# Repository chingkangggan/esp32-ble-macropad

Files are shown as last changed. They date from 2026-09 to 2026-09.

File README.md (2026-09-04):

# ESP32 BLE Macropad

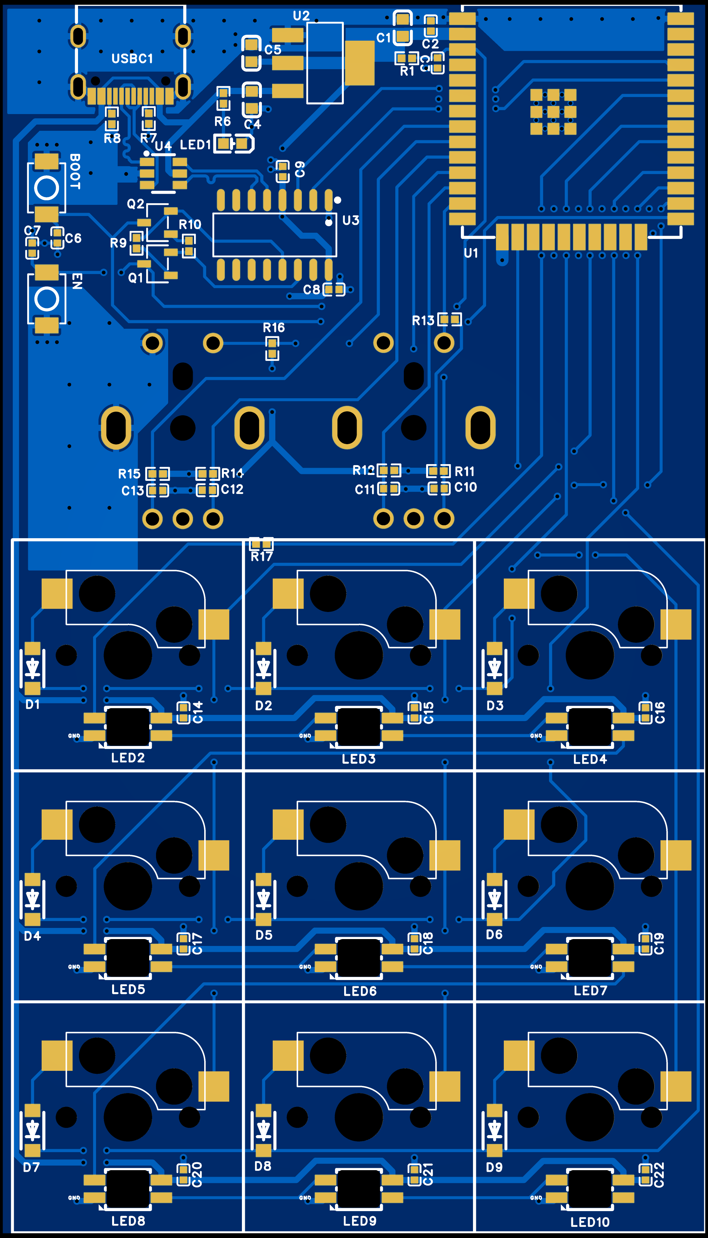
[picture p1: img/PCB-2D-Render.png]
PCB-2D-Render


## Overview
A custom 3x3 hardware macropad firmware powered by an ESP32 micro-controller, featuring dual rotary encoders, persistent NVS flash storage, and interactive Serial CLI configuration.

---

## Key Features

* **BLE Human Interface Device (HID):** Emulates a wireless Bluetooth keyboard using the `BleKeyboard` library.
* **3x3 Matrix Keypad:** Utilizes dynamic row-column scanning with multi-key modifier combination detection (allows declaring keys as either modifier holdings or action triggers).
* **Combo Keys & Layering Support** Allows physical pad buttons to be configured as Modifiers or Action keys. Supports holding single or multiple modifier keys on the pad to trigger layered multi-key macro combinations (up to 5 output HID keys per combo).
* **Dual Rotary Encoders:** Configured via `ESP32Encoder` using hardware PCNT tracking for volume controls, media navigation, and mute toggles.
* **On-the-Fly Serial CLI:** Allows users to map custom keyboard shortcuts, configure modifier rules, and monitor button matrices directly via the Arduino Serial Monitor without re-flashing.
* **Non-Volatile Storage (NVS):** Automatically saves modifier states and shortcut combination maps to onboard flash memory using `Preferences.h`.

---

## Hardware

### Schematics

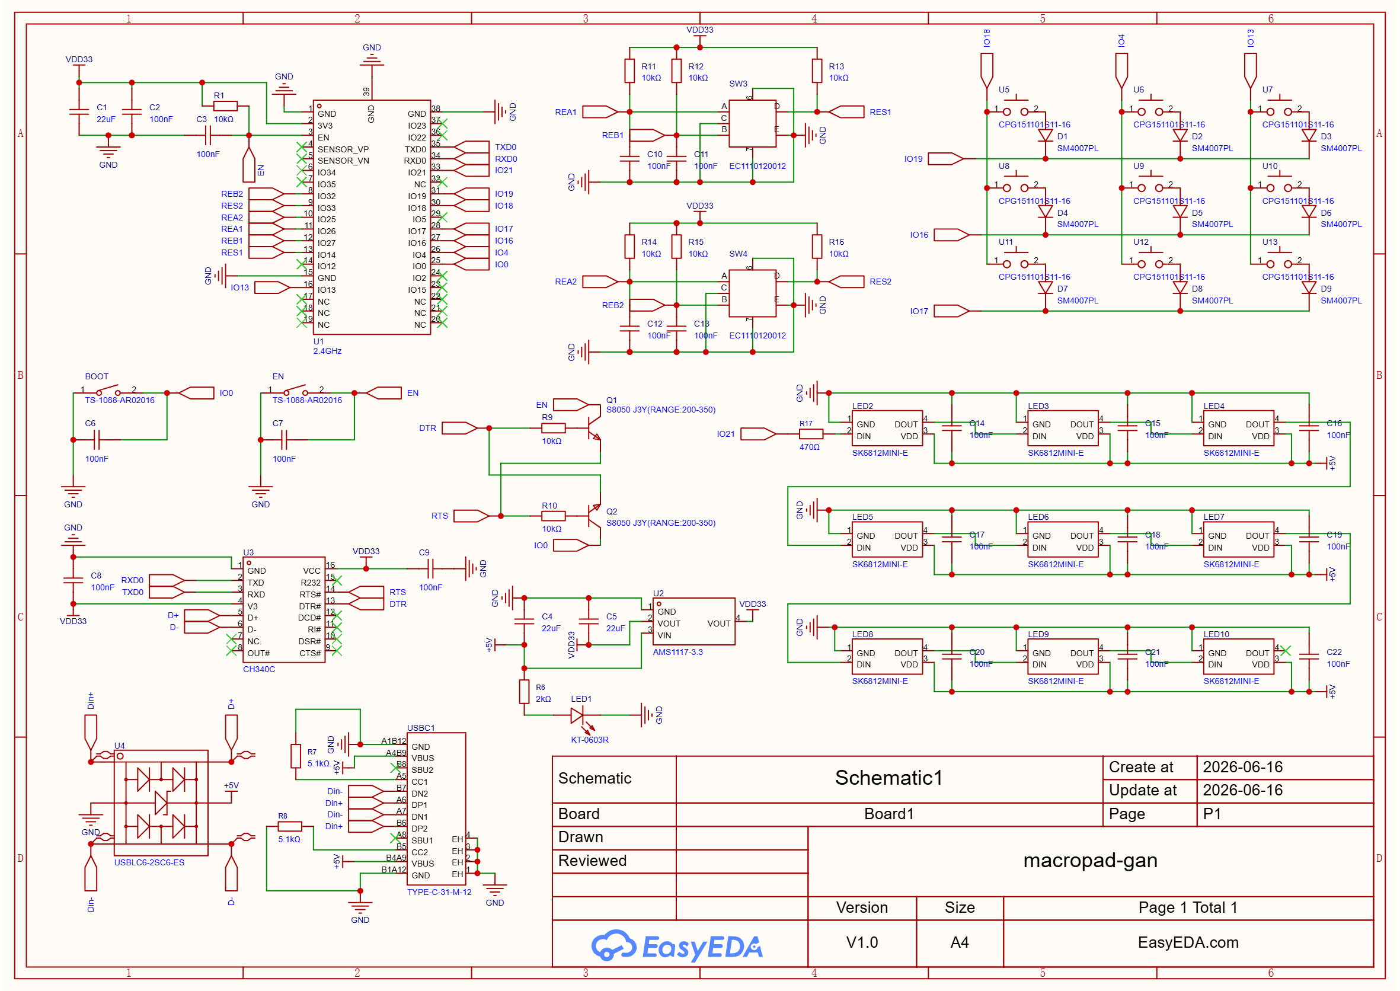
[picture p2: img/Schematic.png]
Schematics


> **Core Circuit Summary:** USB-C powered ESP32 macropad featuring an auto-reset UART flashing circuit, a 3x3 key matrix with anti-ghosting diodes, dual rotary encoders with pushbuttons, and a daisy-chained SK6812MINI-E addressable RGB LED array (optional).

---

#### **1. Power & USB Interface**

* **USB Interface:** USB-C connector protected with a USBLC6-2SC6-ES ESD protection array on the $D+ / D-$ lines.
* **Power Regulation:** Input $+5\text{V}$ from USB-C feeds an AMS1117-3.3 linear regulator to supply a stable $3.3\text{V}$ rail ($\text{VDD33}$) to the microcontroller.
* **Filtering & Indication:** $22\mu\text{F}$ and $100\text{nF}$ decoupling capacitors on the supply rails, featuring a dedicated red power indicator LED (LED1).

---

#### **2. Microcontroller & USB-to-UART Bridge**

* **Core Unit:** ESP32-WROOM module handles primary processing and wireless capabilities.
* **UART Communication:** CH340C USB-to-UART converter interfaces USB data directly to ESP32 hardware serial ports ($\text{TXD0} / \text{RXD0}$).
* **Auto-Reset / Flashing Circuit:** Dual S8050 NPN transistor circuit ($Q1, Q2$) driven by $\text{DTR} / \text{RTS}$ for automated flashing, backed by manual BOOT ($\text{IO0}$) and RESET ($\text{EN}$) tactile buttons with RC debouncing.

---

#### **3. Key Matrix Pinout (3x3 Grid)**

| Row / Line | Key Switches | Anti-Ghosting Diodes |
| --- | --- | --- |
| **Row 1** | U5, U6, U7 | D1, D2, D3 (SM4007PL) | 
| **Row 2** | U8, U9, U10 | D4, D5, D6 (SM4007PL) | 
| **Row 3** | U11, U12, U13 | D7, D8, D9 (SM4007PL) |

---

#### **4. Subsystem Breakdown**

**Dual Rotary Encoders (SW3 & SW4)**

* **SW3:** Encoder channels $A / B$ connected to **REA1** ($\text{IO25}$) & **REB1** ($\text{IO32}$), with integrated switch on **RES1** ($\text{IO14}$).
* **SW4:** Encoder channels $A / B$ connected to **REA2** ($\text{IO27}$) & **REB2** ($\text{IO33}$), with integrated switch on **RES2** ($\text{IO12}$).
* **Debouncing & Pull-ups:** Filtered with $10\text{k}\Omega$ pull-up resistors to $\text{VDD33}$ and $100\text{nF}$ RC capacitors on output channels.

**Addressable RGB LED Matrix** (Optional)

* **LED Array:** 9x SK6812MINI-E RGB LEDs daisy-chained from **IO21** via a $470\Omega$ series resistor.
* **Bypass Filtering:** Individual $100\text{nF}$ decoupling capacitors ($C14 - C22$) placed at every LED $+5\text{V}$ power pin.

---

### PCB Layout

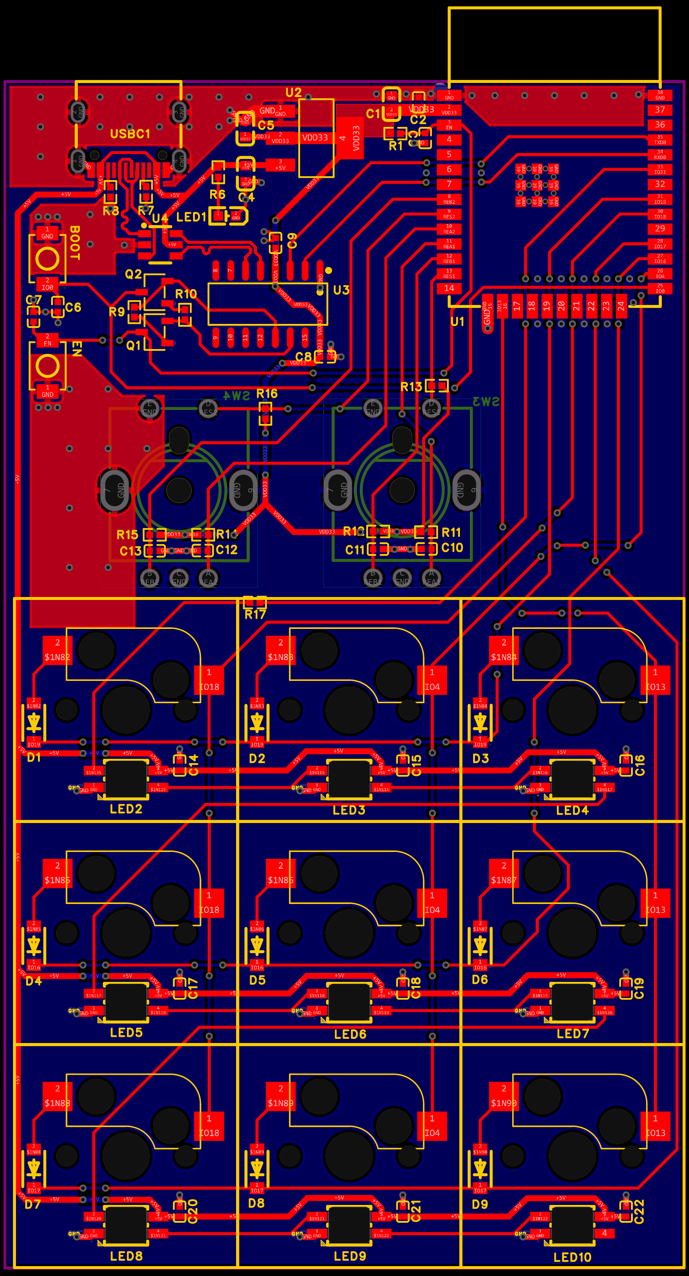
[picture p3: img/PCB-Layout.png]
PCB-Layout


> **Board Layout Overview:** A 2-layer, high-density layout featuring a distinct functional split: dense SMD processing/interface circuitry in the top section, and a spacious 3x3 key grid with integrated per-key SK6812MINI-E reverse-mount/underglow LEDs (optional) across the bottom. The board is designed upside down so most of the components are on the top layer.

---

#### **1. Board Specifications & Design Rules**

* **Layer Count:** 2-Layer Board (Top Layer: Red traces/pours, Bottom Layer: Blue traces/pours)
* **Form Factor:** Compact Macropad layout featuring 9 key switch footprints and dual rotary encoders
* **Copper Pours:** Dedicated ground ($GND$) planes on top and bottom layers for EMI shielding and thermal dissipation

---

#### **2. Layout & Zone Division**

**Processing & Power Zone (Top Half)**

* **USB-C & Interface:** USB-C connector situated at top-left with short, differential pair length-matched trace routing to ESD protection ($U4$) and CH340C ($U3$) serial bridge.
* **Voltage Regulator:** AMS1117-3.3 ($U2$) placed directly near the main power input with wide $+5\text{V}$ and $\text{VDD33}$ copper traces to handle current flow.
* **Control Buttons:** Tactile BOOT and RESET switches placed along the left board edge for quick flashing access.
* **Microcontroller Position:** ESP32-WROOM module ($U1$) occupies the top-right quadrant, oriented with its PCB antenna area positioned along the board edge to optimize wireless signal performance.

**Interactive Matrix Zone (Bottom Half)**

* **Key Matrix Layout:** Uniform $3\times3$ grid housing hot-swap / PCB-mount key switch footprints.
* **Component Placement:** Each key node integrates a dedicated anti-ghosting diode ($D1 - D9$) and a local $100\text{nF}$ bypass capacitor ($C14 - C22$).
* **RGB LED Integration:** SK6812MINI-E addressable LEDs ($LED2 - LED10$) mounted directly under each switch position with daisy-chained data routing running horizontally across the bottom layer.

---

#### **3. Routing & Signal Integrity Highlights**

* **Traces & Vias:** Heavy use of stitching vias around high-current supply nodes and ground planes to reduce loop inductance.
* **Bypass Capacitor Proximity:** Decoupling caps ($C1 - C5$, $C10 - C13$, $C14 - C22$) are placed immediately adjacent to their respective IC and LED power pins.
* **Signal Isolation:** Direct, clean trace runs on top/bottom layers cleanly separating high-speed USB data lines from low-frequency switch matrix lines.

---

## Firmware

```
                               +-----------------------------+
                               |        main.cpp / loop      |
                               +--------------+--------------+
                                              |
      +---------------------------------------+---------------------------------------+
      |                                       |                                       |
      v                                       v                                       v
+-----------------------+           +-----------------------+           +-----------------------+
|   handleSerial()      |           |     readMatrix()      |           |  ESP32Encoder / PCNT  |
|                       |           |                       |           |                       |
| Reads Serial stream   |           | Active-low GPIO scan  |           | Tracks Hardware       |
| into string buffer    |           | updates 16-bit mask   |           | Rotary Encoder steps  |
+-----------+-----------+           +-----------+-----------+           +-----------+-----------+
            |                                   |                                   |
            | Passes raw                        | Passes button state               | Rotated / Clicked
            | command lines                     | bitmask on change                 |
            v                                   v                                   v
+-----------------------------------------------------------------------------------------------+
|                                  Shortcut_Manager (Singleton)                                 |
|                                                                                               |
|  +--------------------------------+   +----------------------------------------------------+  |
|  |       parseCommand()           |   |                   update()                         |  |
|  |                                |   |                                                    |  |
|  | Parses CLI strings:            |   | Detects keypress state changes (pressed & !was)    |  |
|  |  - HELP / SHOW                 |   | Calls sendShortcut(currentButtonState)             |  |
|  |  - MODIFIER <btn>:<0/1>        |   +-------------------------+--------------------------+  |
|  |  - SET <combo>:<key_seq>       |                             |                             |
|  +---------------+----------------+                             | Output HID Keycodes         |
|                  |                                              |                             |
|                  | Syncs changes                                v                             |
|                  v                                +---------------------------+               |
|  +--------------------------------+               |       BleKeyboard         |               |
|  |    ESP32 Preferences (NVS)     |               |                           |               |
|  |                                |               | Sends keypresses/releases |               |
|  | Writes mod_mask & shortcuts    |               | wirelessly over Bluetooth |               |
|  | array to flash memory          |               +-------------+-------------+               |
|  +--------------------------------+                             |                             |
+-----------------------------------------------------------------|-----------------------------+
                                                                  |
                                                                  v
                                                     +--------------------------+
                                                     |       Host Computer      |
                                                     +--------------------------+
```

> Built on the Arduino framework for ESP32, integrating BLE HID keyboard functionality (`BleKeyboard`), hardware PCNT rotary tracking (`ESP32Encoder`), non-volatile storage configuration saving (`Preferences`), and a thread-safe Singleton manager for dynamic matrix key mapping.

---

### 1. Matrix Scanning Mechanism (`readMatrix`)

The 3x3 key matrix relies on standard active-low column scanning using internal GPIO pull-ups to track active key states efficiently into a single 16-bit bitmask (`buttonState`).

* **Pin Configuration:** Rows are assigned to outputs (`19`, `16`, `17`), while Columns use internal pull-up inputs (`13`, `4`, `18`).
* **Active-Low Scanning Loop:**
    1. The scanner iterates through each row, pulling it `LOW` while driving all inactive rows to floating high-impedance (`INPUT`).
    2. Columns are sampled using `digitalRead()`. A logic `LOW` on a column pin signals a closed switch connection.
    3. Pressed keys are recorded directly into an integer bitfield via bitwise shift operations: `currentScanState |= (1 << (j + i * ROWS))`.

* **State Change Detection:** Key evaluation triggers exclusively when the sampled state bitmask differs from `lastButtonState`, minimizing unnecessary polling overhead.

---

### 2. Singleton Pattern: `Shortcut_Manager`

The macro management system uses a thread-safe C++ Singleton pattern to guarantee a single global instance for non-volatile key mappings, serial console interactions, and HID output handling.

* **Singleton Implementation:** Encapsulates initialization logic with a private constructor and deleted copy/assignment operators (`Shortcut_Manager(const Shortcut_Manager&) = delete;`). The global reference is accessed safely via:
```cpp
Shortcut_Manager& manager = Shortcut_Manager::getInstance();

```

* **Bitfield State Engine:** Manages combinations by mapping the 9 physical matrix keys to a bitfield mask (`isKeyModifierMask`) and an array of target HID sequences (`shortcuts[TOTAL_COMBINATIONS][SC_LEN_MAX]`).
* **NVS Storage Integration:** Leverages ESP32 `Preferences` to write modifier masks and multidimensional macro mapping arrays directly into non-volatile Flash storage, retaining custom keybindings across power cycles.
* **CLI Engine:** Includes a built-in Serial terminal interpreter supporting runtime macro management via `HELP`, `SHOW`, `MODIFIER <btn>:<0/1>`, and `SET <combo>:<keys>` commands.

---

### 3. Hardware Encoders & BLE HID Integration

* **Hardware Pulse Counter (PCNT):** Uses `ESP32Encoder` configured with `attachHalfQuad` to handle quadrature decoding in hardware without losing pulses during loop execution.
* **Rotary Media Controls:**
    * Encoder 1 directly emits `KEY_MEDIA_VOLUME_UP` / `KEY_MEDIA_VOLUME_DOWN` keycodes, with its shaft button sending `KEY_MEDIA_MUTE`.
    * Encoder 2 tracks hardware position steps for custom user extensions.

* **BLE Connectivity:** Emulates a standard Bluetooth LE keyboard (`BleKeyboard`), broadcasting parsed multi-key sequences and consumer control signals wirelessly to connected host devices.

---

## Setup & Assembly Guide

### 1. PCB Ordering & Assembly

1. Download the latest release package containing the `Gerber`, `BOM` (Bill of Materials), and `CPL` (Component Placement List) files.
2. Upload the Gerber `.zip` file to your preferred PCB fabricator (e.g., JLCPCB, PCBWay).
3. Enable **SMD Assembly** service:
    * Upload `BOM.csv` and `CPL.csv` when prompted for component placement (covers the core SMD components and CH340C bridge).
    * Verify part orientations against the silkscreen preview before finalizing the order.

4. Once the board arrives, solder the remaining components:
    * **Required Through-Hole Parts:** EC11 Rotary Encoders are **not included** in the default BOM/CPL and require manual sourcing and soldering.
    * **Optional RGB Lighting:** The PCB layout supports SK6812MINI-E reverse-mount LEDs, but they are **not included** in the default BOM/CPL or stock firmware. If you choose to hand-solder them, you will need to add custom LED driving logic to your code.

---

### 2. Firmware Setup (PlatformIO)

1. **Clone the Repository:**
```bash
git clone https://github.com/chingkangggan/esp32-ble-macropad.git
cd esp32-ble-macropad/firmware

```

2. **Open in PlatformIO:**
* Open **VS Code** with the **PlatformIO IDE** extension installed.
* Select **File > Open Folder** and navigate directly to the `firmware` directory.
* *Note: All library dependencies (`ESP32 BLE Keyboard`, `ESP32Encoder`) and board configurations are already defined in `platformio.ini`, so no manual setup is required.*

3. **Flash the Firmware:**
* Connect your board via USB-C.
* Put the ESP32 into bootloader mode if auto-reset isn't triggered (hold `BOOT`, tap `RESET`, release `BOOT`).
* Click **PlatformIO: Upload** in the bottom toolbar, or run:
```bash
pio run --target upload

```

4. **Configure via Serial:**
* Open the PlatformIO Serial Monitor set to `115200` baud.
* Type `HELP` to view available CLI commands for assigning key combinations and modifiers.

---

## Serial CLI Configuration

The onboard Serial Command Line Interface allows real-time macro configuration, modifier toggling, and layout inspection directly through the PlatformIO or Arduino Serial Monitor without re-flashing the firmware.

### **1. Connection Settings**

* **Baud Rate:** `115200`
* **Line Ending:** Both `NL` & `CR` (`\r\n`)

---

### **2. Available Commands**

| Command | Syntax / Parameters | Description | Example |
| --- | --- | --- | --- |
| **`HELP`** | `HELP` | Displays the help menu with all available commands. | `HELP` |
| **`SHOW`** | `SHOW` | Prints the current modifier assignments and active macro combos stored in NVS flash. | `SHOW` |
| **`MODIFIER`** | `MODIFIER <btn_index>:<0/1>` | Configures a pad key as a Modifier holding key (`1`) or a standard Action trigger (`0`). | `MODIFIER 1:1` |
| **`SET`** | `SET <combo_mask>:<key_seq>` | Binds a single key or modifier combo bitmask to a sequence of up to 5 HID keycodes. | `SET 1+2:LCTRL+C` |

---

### **3. Step-by-Step Configuration Examples**

* **Setting a Dedicated Modifier Key:**
To turn Key `1` into a held layer modifier key:
```text
> MODIFIER 1:1
[OK] Key 1 set as MODIFIER.

```

* **Mapping a Multi-Key Macro Combo:**
To map holding Key `1` (Modifier) while pressing Key `2` to trigger `Ctrl + C` (Copy):
```text
> SET 1+2:LCTRL+C
[OK] Combo (1+2) mapped to [LCTRL, C]. Saved to NVS.

```

* **Inspecting Saved Layouts:**
```text
> SHOW
--- Active Configurations ---
Modifiers Bitmask : 0x0002 [Key 1]
Combos:
  [Key 1 + Key 2] -> LCTRL + C
  [Key 0]        -> KEY_MEDIA_VOLUME_UP

```

---

## 3D Printed Enclosure

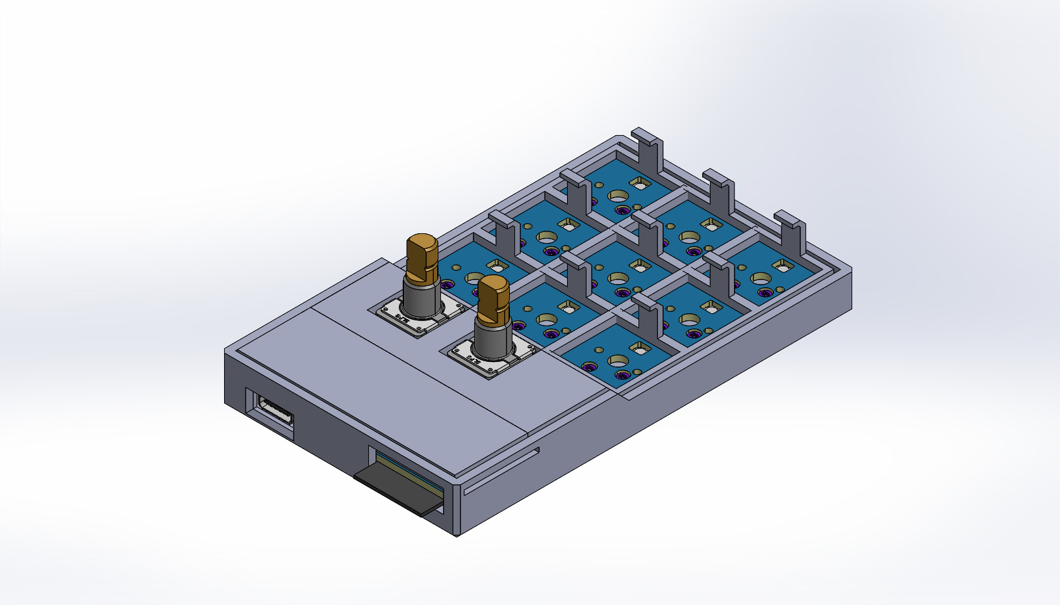
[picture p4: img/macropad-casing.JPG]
Macropad Casing


> **Design Overview:** A custom, low-profile case designed in SolidWorks to house the populated PCB and mechanical switches securely. The enclosure features precise cutouts for the USB-C port, dual rotary encoders, and top-side tactile buttons.

---

### 1. Printing the STL Files

All 3D printable model files are located in the `/mechanical` folder.

| File | Quantity | Recommended Material | Description |
| --- | --- | --- | --- |
| **`top-cover.stl`** | 1 | PLA / PETG | Top plate securing the cover plate to the bottom enclosure |
| **`cover-plate.stl`** | 1 | PLA / PETG | Securing the PCB into the enclosure |
| **`macropad-enclosure.stl`** | 1 | PLA / PETG  | Main housing for PCB |

**Recommended Slicer Settings:**

* **Layer Height:** `0.2mm`
* **Infill:** `15% - 20%` (Grid or Gyroid)
* **Supports:** None required (designed for flat print orientations)

---

### 2. Final Assembly

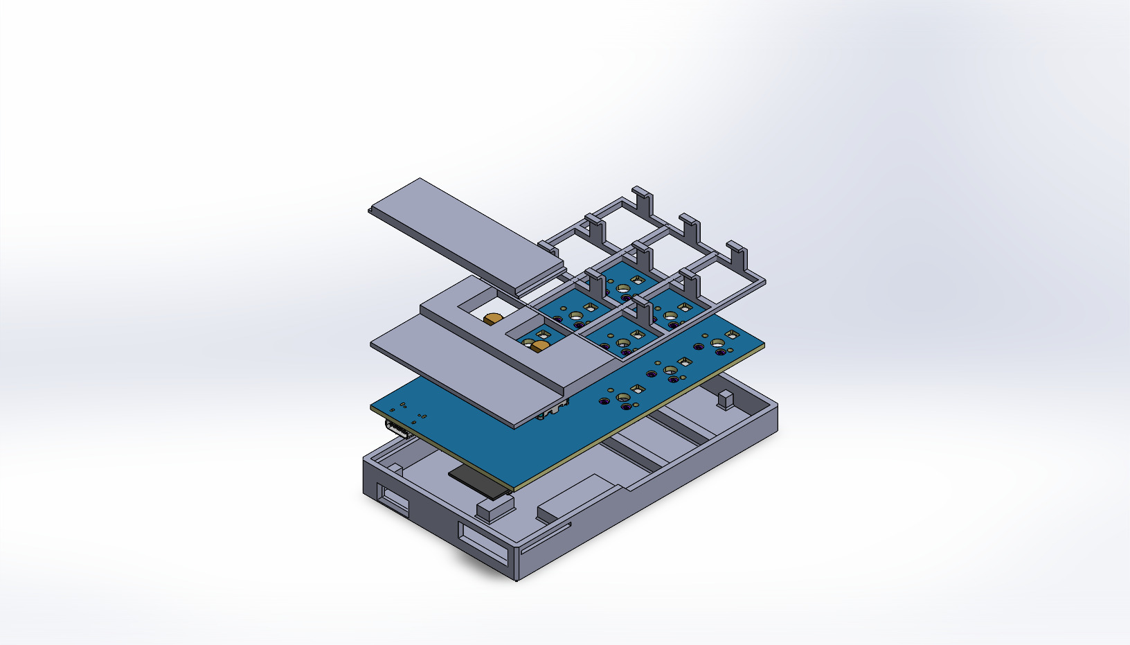
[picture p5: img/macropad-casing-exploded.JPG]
Macropad Casing


1. **Place PCB in enclosure:** Insert PCB into `macropad-enclosure.stl`.
2. **Cover Plate:** Place `cover-plate.stl` on top of the PCB to secure it against the enclosure.
3. **Snap Fit Top Cover:** Snap fit `top-cover.stl` to secure the cover plate against the enclosure.

---

## Credits

Designed and developed by the **Technical Team** of the **IEEE Student Branch (26/27)** at the **University of Nottingham Malaysia**, as part of the **Sparks Initiative 26/27**.

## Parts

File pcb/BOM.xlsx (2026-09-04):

No. | Quantity | Comment | Designator | Footprint | Value | Manufacturer Part | Manufacturer | Supplier Part | Supplier
1 | 2 | TS-1088-AR02016 | BOOT,EN | SW-SMD_L3.9-W3.0-P4.45 |  | TS-1088-AR02016 | XUNPU(讯普) | C720477 | LCSC
2 | 3 | 22uF | C1,C4,C5 | C0603 | 22uF | CL10A226MQ8NRNC | SAMSUNG(三星) | C59461 | LCSC
3 | 19 | 100nF | C2,C3,C6,C7,C8,C9,C10,C11,C12,C13,C14,C15,C16,C17,C18,C19,C20,C21,C22 | C0402 | 100nF | CL05B104KO5NNNC | SAMSUNG(三星) | C1525 | LCSC
4 | 9 | SM4007PL | D1,D2,D3,D4,D5,D6,D7,D8,D9 | SOD-123F_L2.8-W1.8-LS3.7-RD |  | SM4007PL | MDD(辰达半导体) | C64898 | LCSC
5 | 1 | KT-0603R | LED1 | LED-SMD_L1.6-W0.8-R-RD |  | KT-0603R | KENTO | C2286 | LCSC
6 | 9 | SK6812MINI-E | LED2,LED3,LED4,LED5,LED6,LED7,LED8,LED9,LED10 | LED-SMD_4P-L3.2-W2.8-LS5.9_SK6812MINI-E |  | SK6812MINI-E | 欧思科光电 | C5149201 | LCSC
7 | 2 | S8050 J3Y(RANGE:200-350) | Q1,Q2 | SOT-23-3_L3.0-W1.7-P0.95-LS2.9-BR |  | S8050 J3Y(RANGE:200-350) | CJ(江苏长电/长晶) | C2146 | LCSC
8 | 9 | 10kΩ | R1,R9,R10,R11,R12,R13,R14,R15,R16 | R0402 | 10kΩ | 0402WGF1002TCE | UNI-ROYAL(厚声) | C25744 | LCSC
9 | 1 | 2kΩ | R6 | R0402 | 2kΩ | 0402WGF2001TCE | UNI-ROYAL(厚声) | C4109 | LCSC
10 | 2 | 5.1kΩ | R7,R8 | R0402 | 5.1kΩ | 0402WGF5101TCE | UNI-ROYAL(厚声) | C25905 | LCSC
11 | 1 | 470Ω | R17 | R0402 | 470Ω | 0402WGF4700TCE | UNI-ROYAL(厚声) | C25117 | LCSC
12 | 2 | EC1110120012 | SW3,SW4 | SW-TH_EC1110120012 |  | EC1110120012 | ALPSALPINE(阿尔卑斯阿尔派) | C2687281 | LCSC
13 | 1 | 2.4GHz | U1 | WIFI-SMD_ESP32-WROOM-32E | 2.4GHz | ESP32-WROOM-32E-N8 | ESPRESSIF(乐鑫) | C701342 | LCSC
14 | 1 | AMS1117-3.3 | U2 | SOT-223-3_L6.5-W3.4-P2.30-LS7.0-BR |  | AMS1117-3.3 | Advanced Monolithic Systems | C6186 | LCSC
15 | 1 | CH340C | U3 | SOP-16_L10.0-W3.9-P1.27-LS6.0-BL |  | CH340C | WCH(南京沁恒) | C84681 | LCSC
16 | 1 | USBLC6-2SC6-ES | U4 | SOT-23-6_L2.9-W1.6-P0.95-LS2.8-BR |  | USBLC6-2SC6-ES | ElecSuper(静芯) | C5180249 | LCSC
17 | 9 | CPG151101S11-16 | U5,U6,U7,U8,U9,U10,U11,U12,U13 | MX-Hotswap-1u-Antishear |  | CPG151101S11-16 | HanElectricity(瀚源) | C41430893 | LCSC
18 | 1 | TYPE-C-31-M-12 | USBC1 | USB-C_SMD-TYPE-C-31-M-12_1 |  | TYPE-C-31-M-12 | 韩国韩荣 | C165948 | LCSC

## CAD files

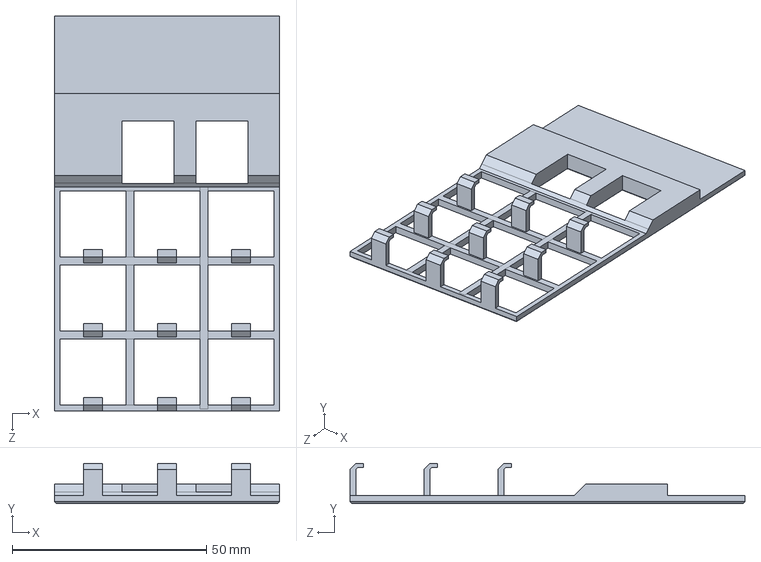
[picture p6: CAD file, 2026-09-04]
3d-print-casing/Solidworks Files/Top Cover.SLDPRT
58.0 x 10.3 x 101.7 mm

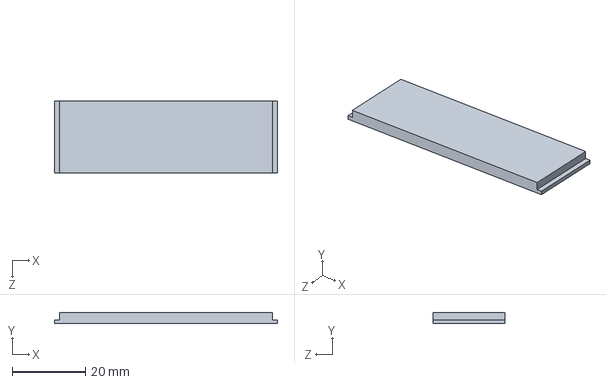
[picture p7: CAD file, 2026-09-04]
3d-print-casing/Solidworks Files/cover plate.SLDPRT
60.7 x 3.00 x 19.5 mm

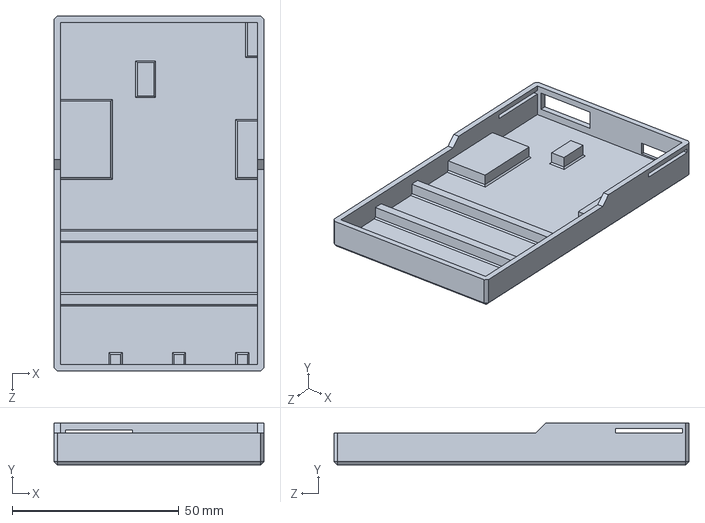
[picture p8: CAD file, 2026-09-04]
3d-print-casing/Solidworks Files/macropad enclosure.SLDPRT
63.0 x 12.6 x 106.5 mm

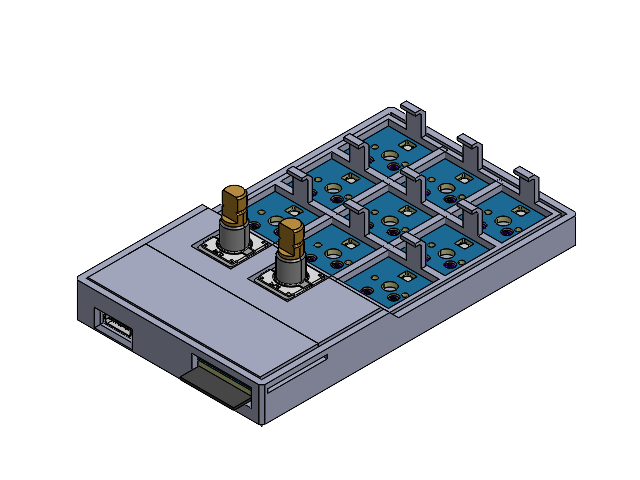
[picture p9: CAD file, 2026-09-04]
3d-print-casing/Solidworks Files/Assem76.SLDASM
SOD-123F_L2.8-W1.8-LS3.7-RD~SOD-123FL_L2.8-W1.8-LS3.7-RD-1~UgUz.step x 9
SOT-23-3_L3.0-W1.7-P0.95-LS2.9-BR~SOT-23-3L_L2.9-W1.6-H1.1-LS2.8-P0.95~DnPa.step x 2
SW-SMD_L3.9-W3.0-P4.45~SW-SMD_L3.9-W2.9-H2.0-LS4.8~hfGq.step x 2
LED-SMD_4P-L3.2-W2.8-LS5.9_SK6812MINI-E~LED-SMD_4P-L3.2-W2.8-LS5.9_SK6812MINI-E~Riab.step x 9
WIFI-SMD_ESP32-WROOM-32E~WIFI-SMD_L25.5-W18.0-H3.1-ESP32-WROOM-32E~ioBK.step
SW-TH_EC1110120012~SW-TH_EC1110120012~8XVv.step x 2
SOT-223-3_L6.5-W3.4-P2.30-LS7.0-BR~SOT-223-4P_L6.5-W3.5-H1.6-LS7.0-P2.30~Us1Z.step
R0402~R0402_L1.0-W0.5-H0.4~TmV3.step x 13
C0603~C0603_L1.6-W0.8-H0.8~kaWv.step x 3
LED-SMD_L1.6-W0.8-R-RD~LED0603_L1.6-W0.8-H0.6~kovA.step
C0402~C0402_L1.0-W0.5-H0.5~WrmB.step x 19
MX-Hotswap-1u-Antishear~SMD_KEYBOARD-SW~G3H6.step x 9
SOP-16_L10.0-W3.9-P1.27-LS6.0-BL~SOP-16_L9.9-W3.9-H1.5-LS6.0-P1.27~PNsV.step
SOT-23-6_L2.9-W1.6-P0.95-LS2.8-BR~SOT-23-6_L2.9-W1.6-H1.5-LS2.8-P0.95~WzFU.step
USB-C_SMD-TYPE-C-31-M-12_1~USB-C_SMD-TYPE-C-31-M-12_1~rk5s.step
Board~Oqpq.step
macropad enclosure
Top Cover
cover plate

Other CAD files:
3d-print-casing/Solidworks Files/Board~Oqpq.step.SLDPRT
3d-print-casing/STL Files/cover-plate.STL
3d-print-casing/STL Files/macropad-enclosure.STL
3d-print-casing/STL Files/top-cover.STL

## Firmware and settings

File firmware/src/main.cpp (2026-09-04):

#include <Arduino.h>
#include <BleKeyboard.h>
#include <ESP32Encoder.h>
#include "shortcutManager.h"

const uint8_t rowPins[ROWS] = {19, 16, 17}; // OUTPUT
const uint8_t colPins[COLS] = {13, 4, 18};  // INPUT

const uint8_t rotaryCLK1 = 27;
const uint8_t rotaryDT1 = 26;
const uint8_t rotarySW1 = 14;
const uint8_t rotaryCLK2 = 32;
const uint8_t rotaryDT2 = 25;
const uint8_t rotarySW2 = 33;

ESP32Encoder encoder1;
ESP32Encoder encoder2;

uint16_t buttonState = 0;
uint16_t lastButtonState = 0;

uint8_t rotaryButtonState1 = 0;
uint8_t rotaryButtonState2 = 0;
uint8_t lastRotaryButtonState1 = 255;
uint8_t lastRotaryButtonState2 = 255;

int32_t rotaryCount1 = 0;
int32_t lastRotaryCount1 = -1;
int32_t rotaryCount2 = 0;
int32_t lastRotaryCount2 = -1;
bool isMuted = false;

BleKeyboard bleKeyboard("ESP32 Macropad");

void readRotaryButton() {
    rotaryButtonState1 = !digitalRead(rotarySW1);
    rotaryButtonState2 = !digitalRead(rotarySW2);
}

void readMatrix() {
    uint16_t currentScanState = 0;
    for (int i = 0; i < ROWS; i++) {
        pinMode(rowPins[i], OUTPUT);
        digitalWrite(rowPins[i], LOW);
        
        for (int j = 0; j < COLS; j++) {
            if (!digitalRead(colPins[j])) {
                currentScanState |= (1 << (j + i * ROWS));
            }
        }
        digitalWrite(rowPins[i], HIGH);
        pinMode(rowPins[i], INPUT);
    }
    buttonState = currentScanState;
}

void decodeKeypressed() {
    Serial.print("[MATRIX] Pressed Keys: ");

    bool anyKeyPressed = false;
    for (int k = 0; k < (ROWS * COLS); k++) {
        if ((buttonState & (1 << k)) != 0) {
            Serial.print("Key ");
            Serial.print(k + 1);
            Serial.print(" ");
            anyKeyPressed = true;
        }
    }

    if (!anyKeyPressed) {
        Serial.print("None");
    }

    Serial.println();
}

void handleSerial() {
    static String inputBuffer = ""; 

    while (Serial.available() > 0) {
        char inChar = (char)Serial.read();

        if (inChar == '\n') {
            inputBuffer.trim();
            if (inputBuffer.length() > 0) {
                Shortcut_Manager::getInstance().parseCommand(inputBuffer);
            }
            inputBuffer = "";
        } 
        else {
            inputBuffer += inChar;
        }
    }
}

void setup() {
    Serial.begin(115200);

    for (int i = 0; i < ROWS; i++) {
        pinMode(rowPins[i], INPUT);
    }
    for (int i = 0; i < COLS; i++) {
        pinMode(colPins[i], INPUT_PULLUP);
    }

    pinMode(rotarySW1, INPUT_PULLUP);
    pinMode(rotarySW2, INPUT_PULLUP);

    ESP32Encoder::useInternalWeakPullResistors = puType::up;

    encoder1.attachHalfQuad(rotaryDT1, rotaryCLK1);
    encoder2.attachHalfQuad(rotaryDT2, rotaryCLK2);

    encoder1.setFilter(1023);
    encoder2.setFilter(1023);

    encoder1.setCount(0);
    encoder2.setCount(0);

    bleKeyboard.begin();
    Shortcut_Manager::getInstance(); // Initialize
}

void loop() {
    handleSerial();
    readMatrix();
    readRotaryButton();

    if (buttonState != lastButtonState) {
        decodeKeypressed();
        Shortcut_Manager::getInstance().update(buttonState, lastButtonState);
        lastButtonState = buttonState;
    }

    rotaryCount1 = encoder1.getCount() / 2;
    rotaryCount2 = encoder2.getCount() / 2;

    if (rotaryCount1 != lastRotaryCount1 || rotaryButtonState1 != lastRotaryButtonState1) {

        if (rotaryCount1 > lastRotaryCount1) {
            bleKeyboard.write(KEY_MEDIA_VOLUME_UP);
        } else if (rotaryCount1 < lastRotaryCount1) {
            bleKeyboard.write(KEY_MEDIA_VOLUME_DOWN);
        }

        if (rotaryButtonState1 && rotaryButtonState1 != lastRotaryButtonState1) {
            bleKeyboard.write(KEY_MEDIA_MUTE);
            isMuted = !isMuted;
        }

        Serial.print("[ROTARY] Count: ");
        Serial.print(rotaryCount1);
        Serial.print(" | SW1: ");
        Serial.print(rotaryButtonState1 ? "PRESSED" : "OPEN");
        Serial.print(" | Mute State: ");
        Serial.println(isMuted ? "MUTED" : "UNMUTED");

        lastRotaryCount1 = rotaryCount1;
        lastRotaryButtonState1 = rotaryButtonState1;
    }
    if (rotaryCount2 != lastRotaryCount2 || rotaryButtonState2 != lastRotaryButtonState2) {

        Serial.print("[ROTARY] ");
        Serial.print("R2 Count: ");
        Serial.print(rotaryCount2);
        Serial.print(" | SW2: ");
        Serial.println(rotaryButtonState2 ? "PRESSED" : "OPEN");

        lastRotaryCount2 = rotaryCount2;
        lastRotaryButtonState2 = rotaryButtonState2;
    }

    delay(10);
}

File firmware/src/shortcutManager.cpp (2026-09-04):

#include "shortcutManager.h"

const Shortcut_Manager::KeyOption Shortcut_Manager::keyOptions[56] = {
    { "NONE", 0 }, { "LCTRL", KEY_LEFT_CTRL }, { "LSHIFT", KEY_LEFT_SHIFT },
    { "LALT", KEY_LEFT_ALT }, { "LWIN", KEY_LEFT_GUI }, { "TAB", KEY_TAB },
    { "ENTER", KEY_RETURN }, { "RETURN", KEY_RETURN }, { "ESC", KEY_ESC },
    { "SPACE", ' ' }, { "UP", KEY_UP_ARROW }, { "DOWN", KEY_DOWN_ARROW },
    { "LEFT", KEY_LEFT_ARROW }, { "RIGHT", KEY_RIGHT_ARROW },
    { "A", 'a' }, { "B", 'b' }, { "C", 'c' }, { "D", 'd' }, { "E", 'e' },
    { "F", 'f' }, { "G", 'g' }, { "H", 'h' }, { "I", 'i' }, { "J", 'j' },
    { "K", 'k' }, { "L", 'l' }, { "M", 'm' }, { "N", 'n' }, { "O", 'o' },
    { "P", 'p' }, { "Q", 'q' }, { "R", 'r' }, { "S", 's' }, { "T", 't' },
    { "U", 'u' }, { "V", 'v' }, { "W", 'w' }, { "X", 'x' }, { "Y", 'y' },
    { "Z", 'z' }, { "0", '0' }, { "1", '1' }, { "2", '2' }, { "3", '3' },
    { "4", '4' }, { "5", '5' }, { "6", '6' }, { "7", '7' }, { "8", '8' },
    { "9", '9' }, { "SLASH", '/' }, { "DOT", '.' }, { "COMMA", ',' },
    { "MINUS", '-' }, { "EQUAL", '=' }, { "BACKTICK", '`' }
};

const int Shortcut_Manager::keyOptionCount = sizeof(Shortcut_Manager::keyOptions) / sizeof(Shortcut_Manager::keyOptions[0]);

Shortcut_Manager::Shortcut_Manager() {
    loadShortcuts();

    Serial.println();
    printHelp();
    printShortcuts();
}

Shortcut_Manager& Shortcut_Manager::getInstance() {
    static Shortcut_Manager instance;
    return instance;
}

void Shortcut_Manager::sendShortcut(uint16_t combinationIndex) {
    if (!bleKeyboard.isConnected()) {
        Serial.println("WARNING: Bluetooth not connected.");
        return;
    }

    bool pressedAny = false;
    for (int slot = 0; slot < SC_LEN_MAX; slot++) {
        uint8_t code = shortcuts[combinationIndex][slot];
        if (code != 0) {
            bleKeyboard.press(code);
            pressedAny = true;
        }
    }

    if (pressedAny) {
        delay(SC_HOLD_TIME_MILLI);
        bleKeyboard.releaseAll();
    }
}

int Shortcut_Manager::parseKeycodeNameToValue(String& keyName) {
    for (int i = 0; i < keyOptionCount; i++) {
        if (keyName == keyOptions[i].name) {
            return keyOptions[i].code;
        }
    }
    return 0;
}

void Shortcut_Manager::loadShortcuts() {
    Preferences preferences;
    preferences.begin("macropad", true);
    if (preferences.isKey("mod_mask")) {
        preferences.getBytes("mod_mask", &isKeyModifierMask, sizeof(isKeyModifierMask));
    } else {
        isKeyModifierMask = 0;
    }

    if (preferences.isKey("shortcuts")) {
        preferences.getBytes("shortcuts", shortcuts, sizeof(shortcuts));
    } else {
        memset(shortcuts, 0, sizeof(shortcuts));
    }

    preferences.end();
}

void Shortcut_Manager::saveShortcuts() {
    Preferences preferences;
    preferences.begin("macropad", false);

    preferences.putBytes("mod_mask", &isKeyModifierMask, sizeof(isKeyModifierMask));
    preferences.putBytes("shortcuts", shortcuts, sizeof(shortcuts));

    preferences.end();
    Serial.println("Configuration saved to NVS Preferences.");
}

void Shortcut_Manager::resetShortcuts() {
    isKeyModifierMask = 0;
    memset(shortcuts, 0, sizeof(shortcuts));

    Preferences preferences;
    preferences.begin("macropad", false);
    preferences.remove("mod_mask");
    preferences.remove("shortcuts");
    preferences.end();
    Serial.println("Flash memory defaults cleared.");
}

void Shortcut_Manager::printShortcuts() {
    Serial.println(F("\n======================================================================"));
    Serial.println(F("                    MACROPAD CONFIGURATION                            "));
    Serial.println(F("======================================================================"));

    Serial.println(F(" [ PHYSICAL KEY STATUS MAP ]"));
    Serial.println(F("  +---+---+---+"));
    
    for (int row = 0; row < ROWS; row++) {
        Serial.print("  | ");
        for (int col = 0; col < COLS; col++) {
            int pinId = (row * COLS) + col;
            bool isMod = (isKeyModifierMask >> pinId) & 1;
            
            Serial.printf("%d:%c | ", pinId + 1, isMod ? 'M' : 'A');
        }
        Serial.println();
        Serial.println(F("  +---+---+---+"));
    }
    Serial.println(F("  (Legend -> M: MODIFIER holding key  |  A: ACTION trigger key)\n"));

    Serial.println(F(" [ ACTIVE CUSTOM SHORTCUTS ]"));
    int activeCount = 0;

    for (int idx = 0; idx < TOTAL_COMBINATIONS; idx++) {
        if (shortcuts[idx][0] == 0) {
            continue; 
        }

        activeCount++;
        String buttonSequenceStr = "";
        
        for (int btn = 0; btn < (ROWS * COLS); btn++) {
            if ((idx >> btn) & 1) {
                if ((isKeyModifierMask >> btn) & 1) {
                    if (buttonSequenceStr.length() > 0) buttonSequenceStr += "+";
                    buttonSequenceStr += String(btn + 1);
                }
            }
        }

        for (int btn = 0; btn < (ROWS * COLS); btn++) {
            if ((idx >> btn) & 1) {
                if (!((isKeyModifierMask >> btn) & 1)) {
                    if (buttonSequenceStr.length() > 0) buttonSequenceStr += "+";
                    buttonSequenceStr += String(btn + 1);
                }
            }
        }

        String keySequenceStr = "";
        for (int k = 0; k < SC_LEN_MAX; k++) {
            uint8_t code = shortcuts[idx][k];
            if (code == 0) break;

            if (keySequenceStr.length() > 0) keySequenceStr += "+";

            bool foundName = false;
            for (int i = 0; i < keyOptionCount; i++) {
                if (keyOptions[i].code == code) {
                    keySequenceStr += keyOptions[i].name;
                    foundName = true;
                    break;
                }
            }

            if (!foundName) {
                if (code >= 32 && code <= 126) {
                    keySequenceStr += String((char)code);
                } else {
                    char hexBuf[8];
                    sprintf(hexBuf, "0x%02X", code);
                    keySequenceStr += String(hexBuf);
                }
            }
        }

        Serial.printf("  SET %-10s : %s\n", buttonSequenceStr.c_str(), keySequenceStr.c_str());
    }

    if (activeCount == 0) {
        Serial.println("  No custom shortcuts mapped.");
    }
    Serial.println(F("======================================================================\n"));
}
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
